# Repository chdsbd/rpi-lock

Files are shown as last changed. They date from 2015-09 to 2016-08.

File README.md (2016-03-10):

# rpi-lock 

## What is this?

This is just a project that allows us to open our door with our student ids instead of having to use a key.

In addition to using our RFID cards we can interact with the lock via a web interface, which enables opening of the door as well as managing of logs.

## Setup

1. Install the scripts

   `git clone https://github.com/chdsbd/rpi-lock && bash rpi-lock/install.sh`

2. Change defaults in `rpi-lock.cfg`

3. Reboot & Profit 💰

## Web Interface Utilizes

- [Flask](https://github.com/mitsuhiko/flask)
- [Jinja2](http://jinja.pocoo.org)
- [Bootstrap](http://getbootstrap.com)
- [Sortable](https://github.com/HubSpot/sortable)
- [Sqlite](https://sqlite.org)

### Circuit Setup Example

Using [HID MultiCLASS RP40 reader](http://www.hidglobal.com/products/readers/iclass/rp40)

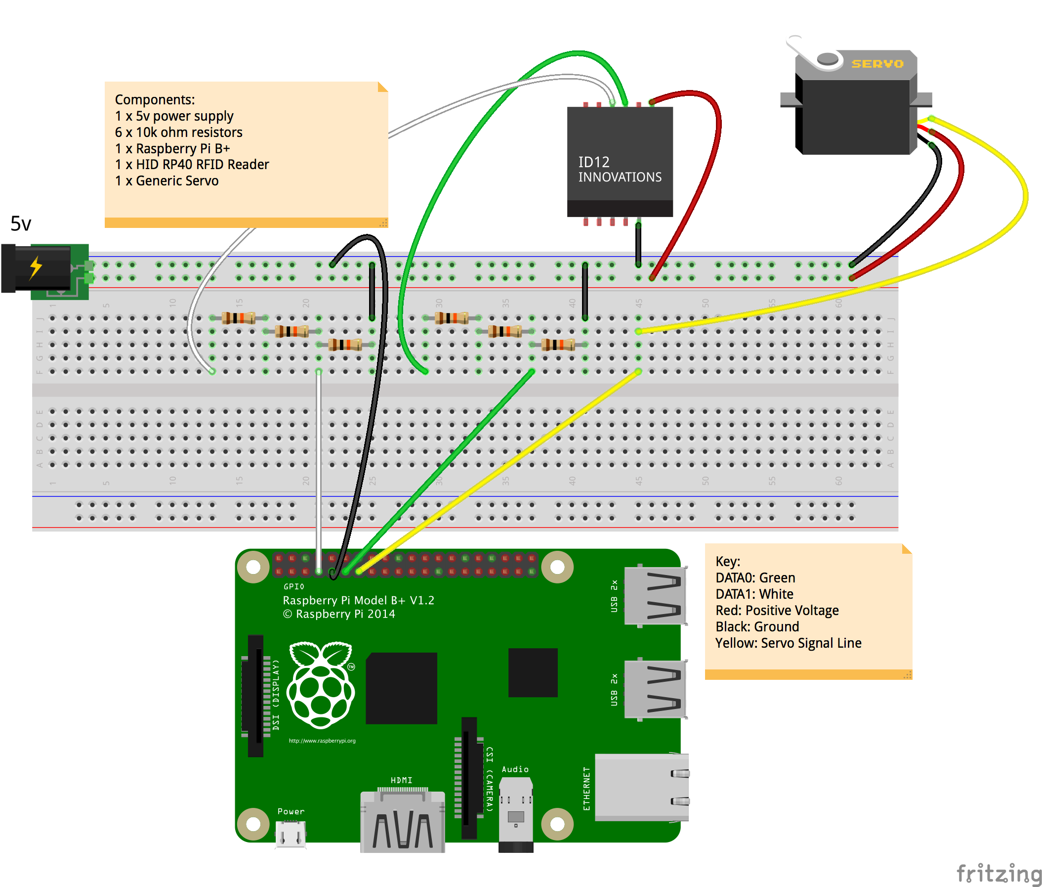
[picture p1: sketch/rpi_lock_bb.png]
sketch


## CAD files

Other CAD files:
models/servo_mount.dwg
models/door_clamp.dwg
models/OldVersions/door_clamp.0010.dwg
models/OldVersions/clamp_assembly.0001.iam
models/OldVersions/door_clamp.0008.ipt
models/OldVersions/door_clamp_back.0006.ipt
models/OldVersions/lever.0001.ipt
models/OldVersions/link.0002.ipt
models/OldVersions/servo_arm.0001.ipt
models/OldVersions/servo_mount.0003.ipt
models/clamp_assembly.iam
models/door_clamp.ipt
models/door_clamp_back.ipt
models/friction-fit-clamp-3d-print.ipt
models/link.ipt
models/servo_arm.ipt
models/servo_mount.ipt

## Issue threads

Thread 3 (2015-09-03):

Bits may drop when reading cards

chdsbd, 2015-09-03:
1-3 bits are dropped from card data when cards are read too quickly in succession.

chdsbd, 2015-09-19:
Bits also switch occasionally, without reading cards quickly.

So instead of `0100101010`, you get `0100101001`, with the last two bits switching for example.
Typically the bits switch early on in the read, rather than towards the end.

chdsbd, 2015-10-10:
Not sure what fixed this but it is no longer an issue.
Maybe separating the servo control into its own module helped.

chdsbd, 2015-10-12:
On the communication branch, which will be merged with master, bits drop periodically.
It seems this occurs if there has been a long duration of inactivity since repeated scans do not result in bits being dropped.

chdsbd, 2016-03-01:
This seems to have been resolved with a removal of the RPIO library in favor of using RPi.GPIO exclusively for GPIO.

Closed 2016-03-01.

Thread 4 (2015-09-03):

Servo gets stuck in place when successful access attempts occur quickly in succession

chdsbd, 2015-09-03:
Calling unlock_door.py again while it is still running causes servo to be stuck in place.
Reading another card after a few seconds resolves the servo issue.

chdsbd, 2015-10-10:
This is no longer an issue. I think this can be attributed to the servo control being in its own module (unlock_door.py) so it is only instantiated once (when it is imported into read_process.py) instead of each time an entry is allowed.

Closed 2015-10-10.

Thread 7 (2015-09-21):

Triggering servo from web while servo is being used by rip_lock breaks RFID reading

chdsbd, 2015-09-21:
If the web button is used to unlock the door while the servo has been recently used by the RFID reader/rpi_lock, then reading from the RFID reader no longer works (program stops running).

chdsbd, 2015-09-23:
Triggering the servo *at all* from the web interface makes the import of `unlock_door.py` in `rpi_lock/read_process.py` temporarily stop working. The only way to open the door is to then use the web interface or wait some time.

chdsbd, 2015-10-10:
This is due to the way we only instantiate the unlock_door.py once when it is imported instead of using subprocess to run unlock_door.py each time a successful card read occurs.

Closed 2015-10-18.

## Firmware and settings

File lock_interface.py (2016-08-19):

#! /usr/bin/env python
# -*- coding: utf-8 -*-
from __future__ import print_function

import sqlite3
import os
try:
    import httplib
except ImportError:
    import http.client as httplib
from functools import wraps
from contextlib import closing
from datetime import datetime
try:
    import configparser
except ImportError:
    import ConfigParser as configparser

import socket
from flask import Flask, render_template, g, redirect, session, request, \
    flash, url_for, abort

app = Flask(__name__)

USERNAME = 'admin'
PASSWORD = 'default'
SECRET_KEY = 'development key'
DEBUG = True
PORT = 5000
DATABASE = os.path.join(os.path.realpath(os.path.dirname(__file__)), "doorlock.db")
RFID_STATUS_FILE = '/tmp/rfid_running'

# use default settings located in this file
app.config.from_object(__name__)

config_file_paths = [os.path.expanduser('~/rpi-lock.cfg'),
                     os.path.join(os.path.realpath(os.path.dirname(__file__)), "rpi-lock.cfg")]
config = configparser.ConfigParser()
config.read(config_file_paths)
try:
    app.config.update(
    USERNAME = config.get("WEB", "USERNAME"),
    PASSWORD = config.get("WEB", "PASSWORD"),
    SECRET_KEY = config.get("WEB", "SECRET_KEY"),
    DEBUG = config.getboolean("WEB", "DEBUG"),
    PORT = config.getint("WEB", "PORT"),
    RFID_STATUS_FILE = config.get("PATH", "RFID_STATUS_FILE"))
except configparser.Error as e:
    print("ConfigParser Error: ", e)


def connect_db():
    return sqlite3.connect(str(app.config['DATABASE']))


def init_db():
    with closing(connect_db()) as db:
        with app.open_resource('schema.sql', mode='r') as f:
            db.cursor().executescript(f.read())
        db.commit()


def login_required(f):
    @wraps(f)
    def wrap(*args, **kwargs):
        if 'logged_in' in session:
            return f(*args, **kwargs)
        else:
            flash('You need to login first.', 'warning')
            return redirect(url_for('login'))
    return wrap


@app.before_request
def before_request():
    g.db = connect_db()


@app.teardown_request
def teardown_request(exception):
    db = getattr(g, 'db', None)
    if db is not None:
        db.close()


def have_internet():
    conn = httplib.HTTPConnection("www.google.com")
    try:
        conn.request("HEAD", "/")
        return True
    except:
        return False


def form_validator(form_values):
    result = True
    for key, value in form_values.items():
        if len(value) <= 0:
            if key != 'note':
                flash('{0} is below min value'.format(
                    key).encode("utf-8"), 'warning')
                result = False
        if len(value) >= 100:
            flash('{0} exceeds max length'.format(
                key).encode("utf-8"), 'warning')
            result = False
        if key == 'binary':
            for char in value:
                if char not in ('0', '1'):
                    flash('String "{0}" is not binary'.format(
                        value).encode("utf-8"), 'warning')
                    result = False
                    break
    return result


@app.route('/')
@login_required
def show_users():
    cur = g.db.execute('''select id, name, note, binary from users
                          order by id desc''')
    users = [dict(id=row[0],
                  name=row[1],
                  note=row[2],
                  binary=row[3]) for row in cur.fetchall()]
    cur = g.db.execute('select binary from log order by id desc limit 1')
    binary = cur.fetchone()
    if binary:
        binary = binary[0]
    return render_template('show_users.html', users=users, binary=binary)


@app.route('/login', methods=['GET', 'POST'])
def login():
    error = None
    if request.method == 'POST':
        if request.form['username'] != app.config['USERNAME']:
            flash('Invalid username', 'danger')
        elif request.form['password'] != app.config['PASSWORD']:
            flash('Invalid password', 'danger')
        else:
            session['logged_in'] = True
            flash('You were logged in')
            return redirect(url_for('show_users'))
    return render_template('login.html', error=error)


@app.route('/logout')
@login_required
def logout():
    session.pop('logged_in', None)
    flash('You were logged out')
    return redirect(url_for('show_users'))


@app.route('/add', methods=['POST'])
def add_user():
    if not session.get('logged_in'):
        abort(401)
    if not form_validator(request.form):
        return redirect(url_for('show_users'))
    g.db.execute('insert into users (name, note, binary) values (?, ?, ?)',
                 [request.form['name'],
                  request.form['note'],
                  request.form['binary']])
    g.db.commit()
    flash('New entry was successfully posted')
    return redirect(url_for('show_users'))


@app.route('/delete', methods=['POST'])
def delete_user():
    if not session.get('logged_in'):
        abort(401)
    g.db.execute('delete from users where id=?', [request.form['user_id']])
    g.db.commit()
    flash('User deleted successfully.')
    return redirect(url_for('show_users'))


@app.route('/log')
@login_required
def show_log():
    cur = g.db.execute('''select id, date, name, binary, status
                       from log order by id desc limit 100''')
    log = [dict(id=row[0],
                date=row[1],
                name=row[2],
                binary=row[3],
                status=row[4]) for row in cur.fetchall()]
    return render_template('show_log.html', log=log)


@app.route('/status')
@login_required
def status():
    status = dict(rfid=os.path.isfile(RFID_STATUS_FILE), net=have_internet())
    return render_template('status.html', status=status)


@app.route('/unlock', methods=['POST'])
@login_required
def unlock_door():
    if request.form['door'] == 'unlock':
        door_unlock()
        g.db.execute('''INSERT INTO log (date, name, binary, status)
                       VALUES(?,?,?,?)''',
                     (datetime.utcnow(), 'Web User', 'Button', '1'))
        g.db.commit()
        flash('Unlocking Door', 'info')
    return redirect(url_for('show_log'))


def door_unlock():
    s = socket.socket(socket.AF_INET, socket.SOCK_STREAM)
    s.connect(("localhost", 5555))
    s.sendall(b'unlock')
    reply = s.recv(1024)
    s.close()
    print("Received reply:", reply.decode("utf-8"))


@app.errorhandler(404)
def page_not_found(error):
    return render_template('404.html'), 404


@app.errorhandler(405)
def method_not_allowed(error):
    return render_template('405.html'), 405


@app.errorhandler(400)
def bad_request(error):
    return render_template('400.html'), 400


@app.errorhandler(500)
def server_error(error):
    return render_template('500.html'), 500

if __name__ == '__main__':
    app.run('0.0.0.0', port=app.config['PORT'])

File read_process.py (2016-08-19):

#!/usr/bin/env python
from __future__ import print_function

import time
import sqlite3
import os
from datetime import datetime

import socket
import RPi.GPIO as GPIO
try:
    import configparser
except ImportError:
    import ConfigParser as configparser

# Default values
data0 = 11
data1 = 7
database = os.path.join(os.path.realpath(os.path.dirname(__file__)), "doorlock.db")
base_timeout = 10
rfid_status_file = "/tmp/rfid_running"

config_file_paths = [os.path.expanduser('~/rpi-lock.cfg'),
                     os.path.join(os.path.realpath(os.path.dirname(__file__)), "rpi-lock.cfg")]
config = configparser.ConfigParser()
config.read(config_file_paths)
try:
    data0 = config.getint("RFID", "DATA0")
    data1 = config.getint("RFID", "DATA1")
    base_timeout = config.getint("RFID", "BASE_TIMEOUT")
    rfid_status_file = config.get("PATH", "RFID_STATUS_FILE").strip("'")
except configparser.Error as e:
    print("ConfigParser Error: ", e)

timeout = base_timeout
bits = ''


def gpio_setup():
    GPIO.setmode(GPIO.BOARD)
    GPIO.setup(data1, GPIO.IN)
    GPIO.setup(data0, GPIO.IN)
    GPIO.add_event_detect(data1, GPIO.FALLING, callback=one)
    GPIO.add_event_detect(data0, GPIO.FALLING, callback=zero)


def connect_db():
    return sqlite3.connect(database)


def one(channel):
    global bits
    global timeout
    bits = bits + '1'
    timeout = base_timeout


def zero(channel):
    global bits
    global timeout
    bits = bits + '0'
    timeout = base_timeout


def loop():
    global timeout
    global bits
    print('Ready')
    while True:
        if len(bits) > 0:
            timeout -= 1
            if timeout == 0:
                process_card(bits)
                bits = ''
                timeout = base_timeout
        time.sleep(.001)


def process_card(binary):
    name, status = auth_status(binary)
    if status:
        print(u'Allowed "{}" entry.'.format(name))
        unlock()
        log(status, binary, name)
    else:
        print('Disallowed:', binary)
        log(False, binary)


def auth_status(bit_query):
    con = connect_db()
    with con:
        cur = con.cursor()
        cur.execute(
            'SELECT name FROM users WHERE Binary = ?', [bit_query])
        row = cur.fetchone()
        if row is None:
            return row, False
        else:
            return row[0], True


def unlock():
    s = socket.socket(socket.AF_INET, socket.SOCK_STREAM)
    s.connect(("localhost", 5555))
    s.sendall(b'unlock')
    reply = s.recv(1024)
    s.close()
    print("Received reply:", reply.decode("utf-8"))


def log(status, binary, name=None):
    if len(binary) < 10:
        pass
    else:
        con = connect_db()
        with con:
            cur = con.cursor()
            cur.execute('''INSERT INTO log (date, name, binary, status)
                           VALUES(?,?,?,?)''',
                        (datetime.utcnow(), name, binary, status))


def main():
    try:
        open(rfid_status_file, 'w')
        gpio_setup()
        loop()
    except KeyboardInterrupt:
        os.remove(rfid_status_file)
        GPIO.cleanup()
        print('Clean Exit.')

if __name__ == '__main__':
    main()

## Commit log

2015-08-08 fixed error with missing card_database.db file
    [add_card.py]
2015-08-12 scripts to test servo
2015-08-12 Added inventor models and updated README
    [clamp_assembly.0001.iam, clamp_assembly.iam, door_clamp.0008.ipt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]
2015-08-20 widened cut for shaft
    [door_clamp.0009.dwg, door_clamp.0010.dwg, door_clamp.dwg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]
2015-08-20 Created 3d printable clamp
    [friction-fit-clamp-3d-print.ipt]
2015-08-26 Created servo mount drawing
    [servo_mount.0003.ipt, servo_mount.dwg, servo_mount.ipt]
2015-08-29 added fix for servo arm to README
    [read_process.py]
2015-08-30 removed tabs and sign in button from login page
2015-08-30 fixed flashing not flashing errors red
    [lock_interface.py]
2015-08-30 fixed error in validator
    [lock_interface.py]
2015-08-30 fixed login screen errors
    [lock_interface.py]
2015-08-30 Added sorting to tables + formatting + minor fixes
    [lock_interface.py]
2015-08-31 added code to check status of Raspberry Pi
2015-08-31 Revert "added tests & removed junk + minor edits"
    This reverts commit 055a6b24519a5f18ec6671c69f833443c13163fd.
    [lock_interface_tests.py]
2015-08-31 Revert "Revert "added tests & removed junk + minor edits""
    This reverts commit 2a2de22e14271418c6fb994c7eeddc62989be10e.
    [lock_interface_tests.py]
2015-08-31 removed unlock button from login page
2015-08-31 Potentially simplified add_user.py 😕
2015-09-01 changed name of column from device to note
2015-09-01 fixed typo with RFID_STATUS_FILE causing bad RPi status
    [read_process.py]
2015-09-01 fix typo in lock_interface.py, updated TODO
    [lock_interface.py]
2015-09-02 fixed bug with card reads not working after using web button
    [read_process.py, unlock_door.py]
2015-09-02 added responsive tables fixed button padding
2015-09-02 fixed bug with duplicate entries being made into log table
    [unlock_door.py]
2015-09-02 fixed import and increase timeout for reader
    [read_process.py, unlock_door.py]
2015-09-06 Added sketch of circuitry
    [rpi_lock.fzz]
2015-09-18 refined servo range
2015-09-21 Re-added logging for web button use
2015-10-13 Revert "Bind only to localhost"
    This reverts commit 3eec02dffacb45349b77af0727addb18d8753627.
    [unlock_door.py]
2015-10-18 updated formatting, culled the junk in the readme 🔥
2015-10-19 added install.sh & updated readme 🌊
2015-10-20 Added python 3 support and added configuration file
    [example-rpi-lock.cfg]
2015-10-20 add "lite" install ☀️
2015-10-28 Fix issue with configuration from giving bad types
    [example-rpi-lock.cfg]
2015-11-01 updated formatting - linters are great 😊
2016-01-31 Replaced RPIO library usage with RPi.GPIO
    [example-rpi-lock.cfg]
2016-03-01 Replaced ZeroMQ with standard library socket
    [lock_interface.py, read_process.py, unlock_door.py]
2016-03-10 Fixed install script, simplified overall configuration. 🎆
    [example-rpi-lock.cfg]
2016-08-19 🐛Corrected parsing of config file
    [lock_interface.py, read_process.py, unlock_door.py]
